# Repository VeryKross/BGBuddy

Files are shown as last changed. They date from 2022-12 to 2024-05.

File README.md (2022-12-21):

# BGBuddy
BG Buddy is a blood glucose monitoring project that provides a local IoT-based display for Nightscout users.

BG Buddy leverages the ESP8266 SOC, an inexpensive OLED display, and a few other optional components. Since BG Buddy depends on a user's Nightscout website for data, this has to be setup and operational before anything wonderful can come from BG Buddy. If you're not familiar with Nightscout, please refer to this link for all the details and come back here once you're setup: http://www.nightscout.info/

This initial version of BG Buddy simply monitors the Nightscout API and displays 5 key pieces of information which, for me, would cause me to check on a loved one with diabetes if any of the values were out of range. That's really what's at the core of BG Buddy - keep those key values top-of-mind by creating a simple inexpensive device that could sit on a desk or shelf [or both] so these critical values are always available, at a glance. See the Wiki for planned updates.



BG_Buddy1_Breadboard1

The full build and setup instructions, bill of materials and other info can be found in a PDF document in the version (v1) folder. This covers both source and compiled bin options so if you really don't want to get into compiling stuff and just want a working BG Buddy, that's an option too!

BG Buddy is a DIY project intended for educational and personal use only. It is not intended for commercial use or to be relied upon for any professional or medical purposes. The creators and contributors of BG Buddy are not responsible for any damages or injuries that may result from the use of this project. By using the BG Buddy software and/or hardware plans, you acknowledge that you understand and assume all risks associated with its use. Please use caution and common sense when working on any DIY project.

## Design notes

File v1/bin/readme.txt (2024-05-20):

The bin file here is a compiled version of the program in the src folder.

NOTE: The IdeaSpark versions are only for the IdeaSpark ESP8266 with built-in OLED screen. Don't use these if building the project from the documentation with the separate ESP8266 and SSD1306 OLED components. Note also that there are two versions of the IdeaSpark binary, SDA12 and SDA14. This corresponds to whether your particular IdeaSpark package is using the GPIO12 pin or the GPIO14 pin for the screen's data connection (OLEDSDA). Check the documentation/diagram for your IdeaSpark to know which binary is right for you. If you're not sure, reach out to me.

To install the bin file into your ESP8266 processor, use a ROM "flasher" like the one from ESPHome Flasher: https://github.com/esphome/esphome-flasher/releases

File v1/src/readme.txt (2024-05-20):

This folder contains the BG Buddy v1 source file. It can be loaded directly into 
the Arduino IDE, compiled, and flashed to your ESP8266 processor without making any changes.

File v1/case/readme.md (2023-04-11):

# 3D Printable Case
This is a [very] basic case that I created to be 3D printed for BG Buddy. I should be printable without any supports on nearly any FDM (filament style) printer, and it will work equally well with PLA, PETG or whatever your favorite filament type is.

The case is a snap together design that doesn't require any glue other than the hot glue you might use to mount the SOC and OLED screen.

In addition to the top and base of the case, I've also included a separate "frame" for the OLED - I found this to be the trickiest bit to design and so by providing it separately, I hope to make it easier for anyone else who might want to use this frame within their own case design just to save some time and trouble. If you just want the case as-is, just print the top and base and ignore the frame.

Here's a picture of the printed case using PLA with a .28 layer hight - it would come out much cleaner if you print at higher quality setting.


If you are using the IdeaSpark "all in one" processor, the one with the ESP8266 and OLED mounted together as one unit, I've uploaded a new case that works well for it. Just download and print the three IdeaSparkCase files - they don't require any supports for printing. When operating, the blue activity LED is just visible through the plastic in the top-right corner (depending on what color filament you use of course).



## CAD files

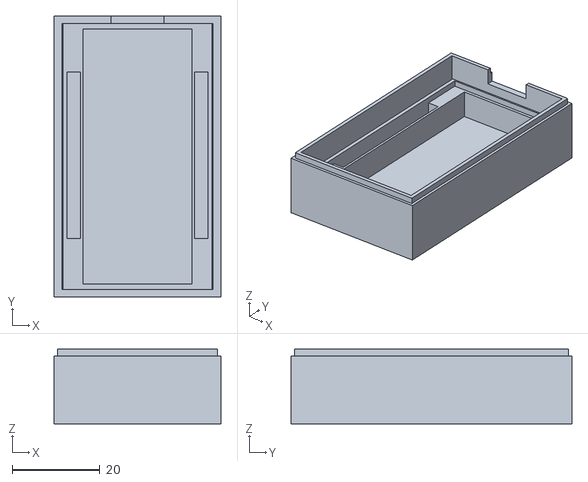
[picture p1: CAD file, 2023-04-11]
v1/case/IdeaSparkCase_Bottom3.stl
38.0 x 64.0 x 17.0

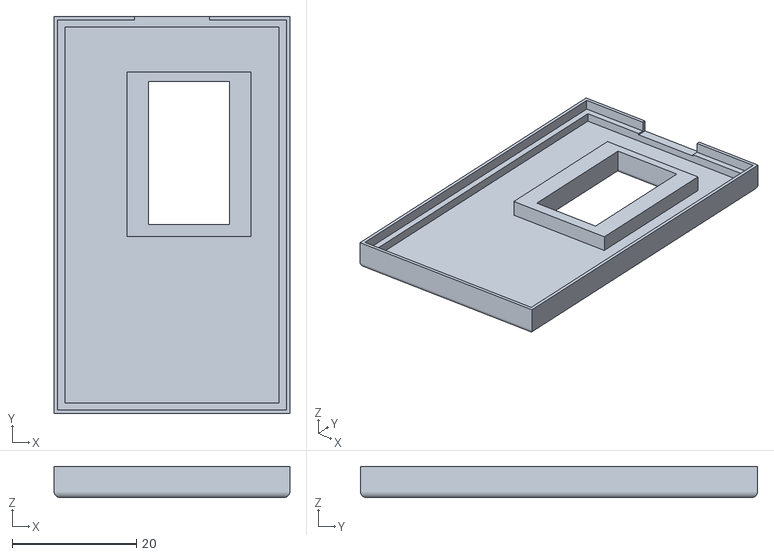
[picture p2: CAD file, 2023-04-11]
v1/case/IdeaSparkCase_Top2a.stl
38.0 x 64.0 x 5.00

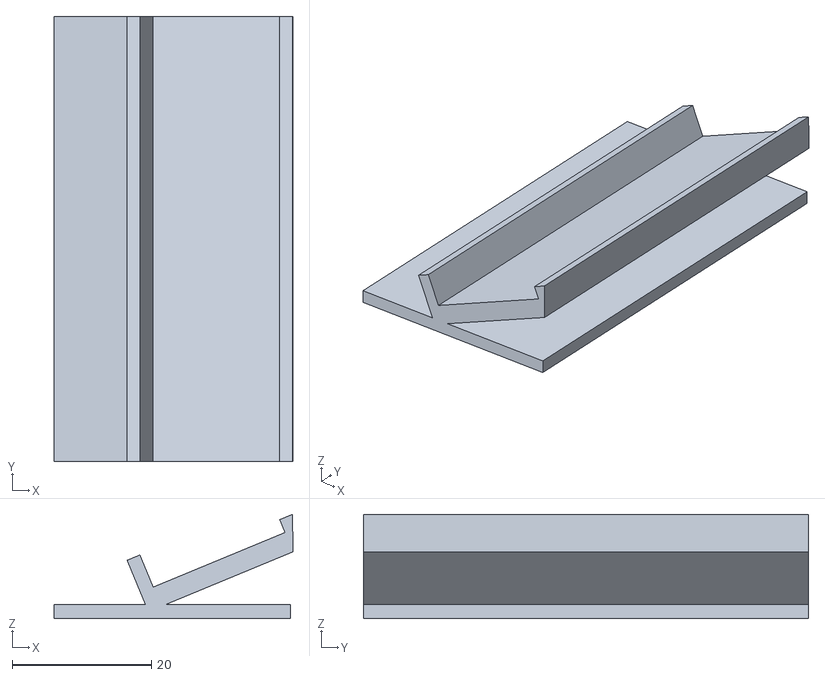
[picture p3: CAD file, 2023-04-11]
v1/case/IdeaSparkCase_Stand2.stl
34.4 x 64.0 x 15.0

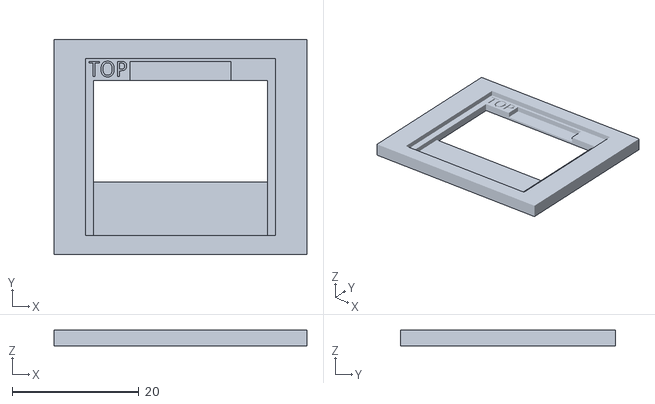
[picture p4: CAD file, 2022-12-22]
v1/case/BG Buddy_OLED_Frame.stl
40.0 x 34.0 x 2.50

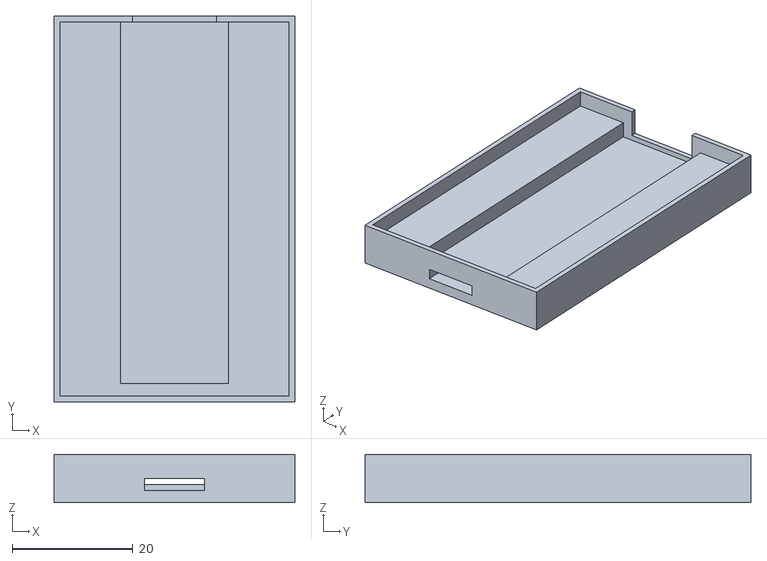
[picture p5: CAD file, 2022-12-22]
v1/case/BG Buddy_base.stl
40.0 x 64.0 x 8.00

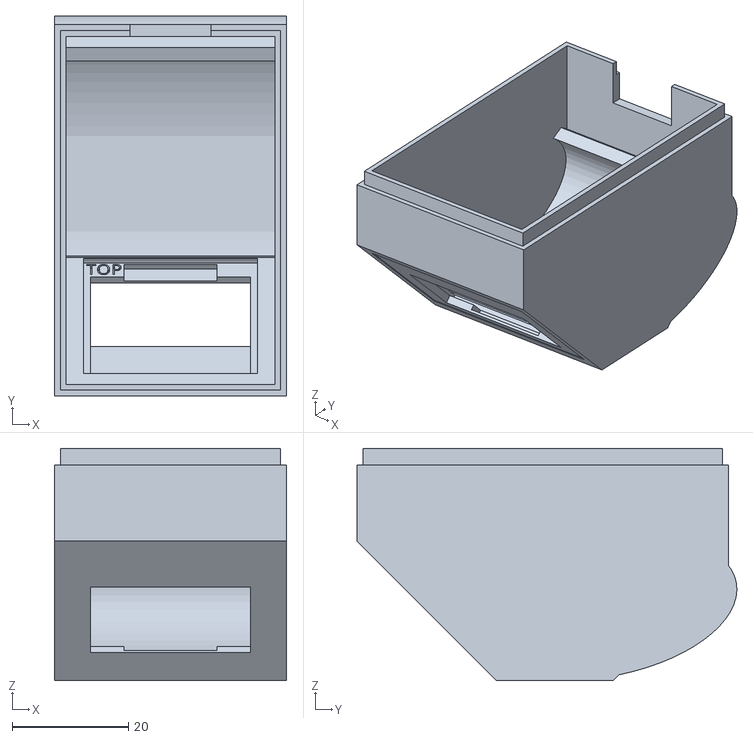
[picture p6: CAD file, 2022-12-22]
v1/case/BG Buddy_top.stl
40.0 x 65.5 x 40.0

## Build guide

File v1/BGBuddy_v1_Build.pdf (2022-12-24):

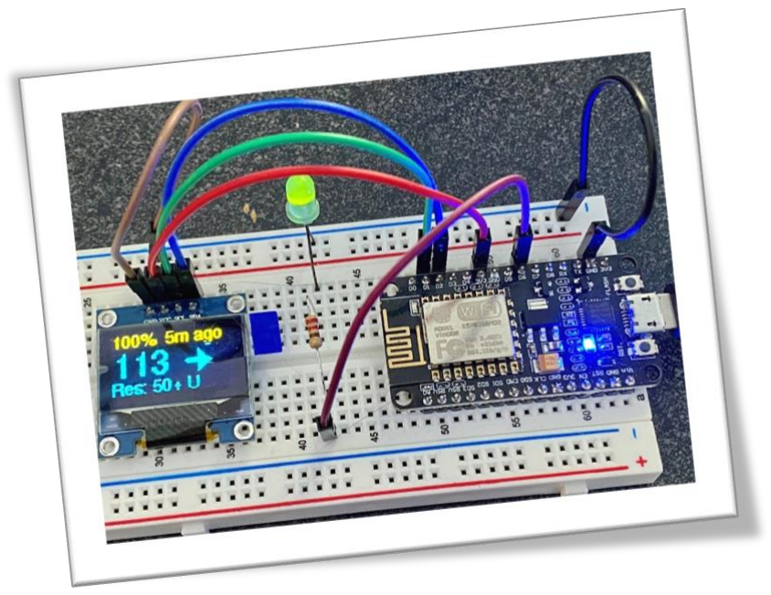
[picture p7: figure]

HTTPS://GITHUB.COM/VERYKROSS/BGBUDDY | 1

# Blood Glucose Buddy v1

## Introduction

BG Buddy is a blood glucose monitoring project that provides a local IoT-based display for Nightscout users. As such, BG Buddy is currently only usable for people that have a working Nightscout site setup that they are publishing their data to via their CGM or the Loop mobile app. It is beyond the scope of this document to explain Nightscout so please refer to this link: http://www.nightscout.info/

In terms of hardware, BG Buddy leverages the ESP8266 SOC, an inexpensive OLED display, and a few other optional components. It’s easy to put together and depending on where you get the components, you can be up-and-running for well under $20 USD!

Version 1 (v1) of BG Buddy simply monitors the Nightscout API and displays 5 key pieces of information. For me, these are the values that would cause me to get up and check on a loved one with diabetes if any of them were out of range. Really, that’s what's at the core of BG Buddy - keep those key values top-of-mind and glanceable by creating a simple, inexpensive device that can sit on a desk or shelf [or both] so that these critical values are always visible. In addition, it will also light up an LED approx. every minute when it’s refreshing the data.

Looking ahead, the next version of BG Buddy will be adding alerts in the form of both visual (another LED) and audible (buzzer). These alerts will be driven off your Nightscout alarm settings, so no additional setup is needed within BG Buddy itself. You will, however, be able to turn off the alerts [and if your version of BG Buddy doesn’t have the extra LED or buzzer, you won’t get the alerts anyway].

As is stated on our GitHub site, BG Buddy is a DIY project intended for educational and personal use only. It is not intended for commercial use or to be relied upon for any professional or medical purposes. The creators and contributors of BG Buddy are not responsible for any damages or injuries that may result from the use of this project. By using the BG Buddy software and/or hardware plans, you acknowledge that you understand and assume all risks associated with its use. Please use caution and common sense when working on any DIY project.

## Building BG Buddy

### Overview

Now, if you found that photo of a bunch of wires and gadgets plugged into some kind of board with a bunch of holes in it a little bit scary, stay with me – I got you That’s just a project “breadboard”; it’s an easy way for DIY tinkerers to play with electronics components and create circuits without having to solder wires together. If you don’t have one, and aren’t interested in getting one, no worries – we can get by without it, especially if we’re just creating a BG Buddy to use [not tinker with].

When we take a more abstract look at what makes up BG Buddy from the hardware perspective, there are just two(2) main parts and two(2) optional parts.

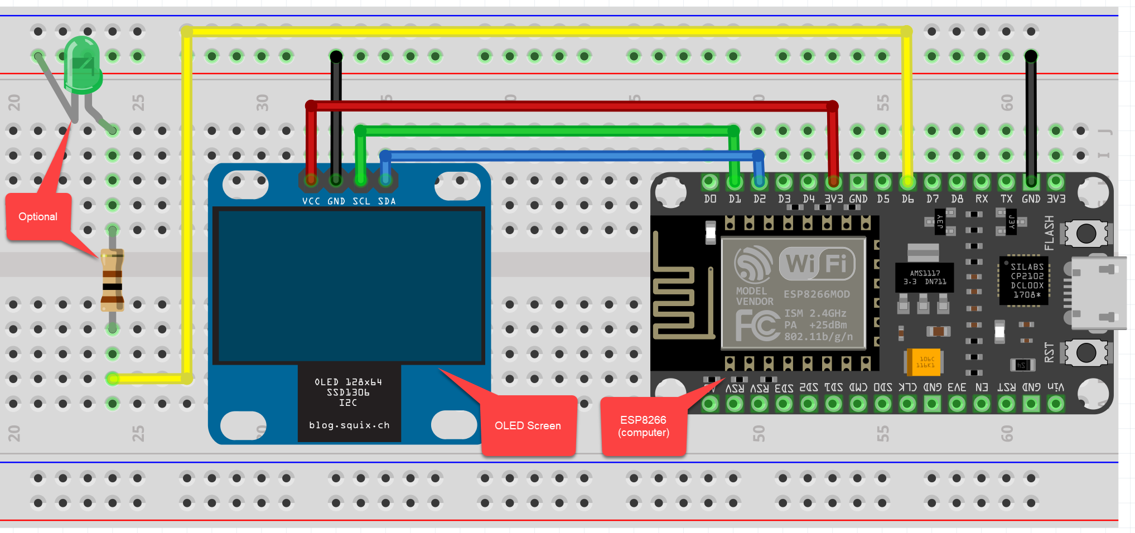
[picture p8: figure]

We need the ESP8266 since that’s the “computer” (SOC – System On a Chip) and we need the little OLED screen so we can display our BG values. The two optional components, a green LED and a resister, are used together so BG Buddy can light up a green status LED when it’s getting fresh data; if you can live without seeing that activity, you can leave those out and, besides, I also light up the blue LED built into the SOC as a secondary busy indicator so you can always refer to that.

The ESP8266 has a micro USB plug on it which is where it gets power from and is how we program it by plugging it into your PC (Windows or Mac). Once programmed, it just needs power and that can come from almost any USB charging adapter you have lying around.

The OLED screen connects to the ESP8266 with just four (4) wires; you’ll want to be careful about following the directions here because depending on the manufacturer of these OLED screens, they sometimes rearrange the order of the four(4) pins that the wires connect to so, for example, instead of VCC, GND, SCL, SDA like in the diagram above, they might be GND, VCC, SCL, SDA instead. Also, I’ll show you how to do this without any soldering to make it super easy. If you hook everything up and the screen stays blank though, double check the order of those pins first!

### Bill of Materials (BOM)

Alright, as I mentioned above, there are just two things you need; the ESP8266 SOC and the OLED. If I’m totally honest, yes, you’ll need some wires too…and probably a case…and maybe some hot glue. The point is, you don’t need much and you don’t need special tools or skills to have a fully functional BG Buddy, just like this one using just.4.wires :

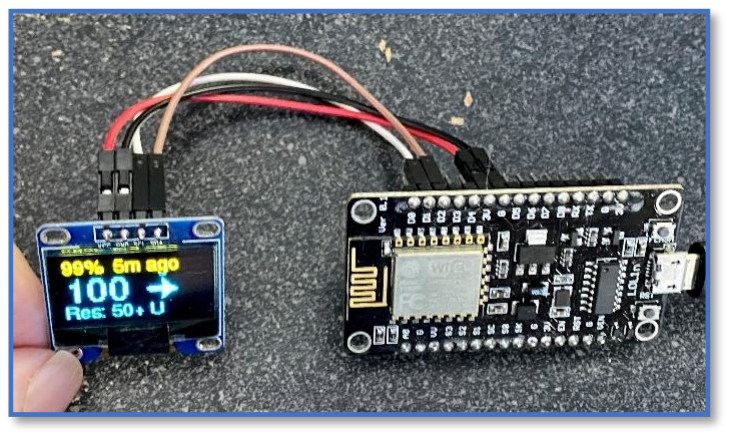
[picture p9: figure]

Now for the shopping list, I’ve tried to give you two options – ordering from Amazon or ordering from AliExpress. I’ve ordered components from both and will happily do so again; I’ve had great experiences with AliExpress, and the prices are amazing, but it will take longer to get your parts (2-3 weeks usually). You’ll also want to pay very close attention to what you’re ordering, not because they’re trying to scam you but because a single listing sometimes has several product variations, and you’ll want to be sure you’ve selected the one you want. Don’t assume that because the picture looks right, that the correct product/variation has been selected. Click it and confirm the price before adding to your cart.

The links and prices I’ve quoted are in US dollars so if you’re outside of the US, check your local sources for equivalent products. Local to me I’ve also found all of these items at local electronics stores so if you have that option, check it out.

The must have parts:

- ESP8266 SOC [the “computer”]
- Amazon: (3-pack ~$16USD) https://www.amazon.com/KeeYees-Internet-Development-Wireless-Compatible/dp/B07HF44GBT/
- Ali Express: (1 count ~ $3USD)
https://www.aliexpress.us/item/2251832478785371.html
- SSD1306 OLED [the display screen]
- Amazon: (1 count ~ $7USD) https://www.amazon.com/UCTRONICS-SSD1306-Self-Luminous-Display-Raspberry/dp/B072Q2X2LL/
- Ali Express: (1 count ~ $3.50USD - be sure to select the correct 4-pin yellow/blue display) https://www.aliexpress.us/item/2251832709890624.html
- Wires [to directly connect the above components]
- Amazon: (40 count female-to-female 4" ~ $6USD) https://www.amazon.com/dp/B077N58HFK
- Ali Express: (1 pack 40 count female-to-female 10cm [4"] ~ $2.50USD) https://www.aliexpress.us/item/2251832638800607.html

As you can see, there’s quite a price difference [between Amazon and AliExpress] and you’ll note that in some cases there’s a difference in the minimum # of parts you can order (the smallest quantity of ESP8266 devices you can buy on Amazon is a 3-pack). If you’re planning to make more than one BG Buddy, probably not a big deal. Otherwise, especially if ordering from Amazon, you may want to see if you can split an order with some other local folks who want their own BG Buddy – you’ll certainly have more than enough wire!

When we get into the optional components, like the green LED, things get worse in terms of minimum quality; it’s very hard to find LEDs in quantities of less than 60 or resisters in packs of less than 100, and you only need one(1) resister per green LED. Now, if you’re someone who likes to tinker with electronics and other DIY projects, that’s probably not an issue and even these large quantities are still very inexpensive. Of course, if you are a DIY sort of person, you probably already have some LEDs and resisters lying around

The optional parts:

- Green LED (constant or blinking variety)
- Amazon: (60 count, multi-color, non-blinking ~ $6USD) https://www.amazon.com/dp/B01C3ZZT2I
- Ali Express: (100 count, multi-color, non-blinking ~ $2.50USD) https://www.aliexpress.us/item/2251832545092387.html
- 100-220 Ohm resistor (depends on LED brightness desired)
- Amazon: (100 count 200ohm ~ $6USD) https://www.amazon.com/EDGELEC-Resistor-Tolerance-Resistance-Optional/dp/B07HDGH1R1
- Ali Express: (100 count, be sure to select 200R [for 200 ohm] ~ $3USD) https://www.aliexpress.us/item/3256801441680644.html
- Project board (aka Breadboard)
- Amazon: (board & wires kit, some components won't be needed ~ $11USD) https://www.amazon.com/dp/B09TX9CMG1
- Ali Express: (board without wires ~ $4USD) https://www.aliexpress.us/item/3256801539488877.html
- Wires for breadboard
- Amazon: (120 count 4” variety pack of female-to-female, male-to-male & male-female ~$7USD) https://www.amazon.com/dp/B07GD1XFWV?th=1

As mentioned above, you only need the green LED if you want to have a “busy” status light that you can locate wherever you’d like (handy if you want to poke it through the outside of a case). To use it, and the resister [do not try and use the LED without a resister … bad things will happen], you will almost certainly need to solder things together so be prepared for that. I’ll also point out that if you decide to upgrade to the v2 BG Buddy later, the one with alerts, you’ll be adding a red LED to the kit for the visual alert. So, if you do decide to buy a pack of LEDs, maybe make it a variety pack so you have both the green and red LEDs … just in case

The breadboard listed here is only needed if you want to start tinkering with this DIY electronics stuff – if your goal is to just assemble BG Buddy and pop it in a case, you don’t need the breadboard. Also, if you do decide to get the breadboard, you’ll need some wires in addition to those in the “must have” list – you need wires with exposed ends you can poke into the holes in the breadboard. Because of that, I’ve listed a breadboard on Amazon that comes with a set of appropriate wires for about the same price as buying a breadboard and set of wires separately.

BTW, a quick note regarding the OLED screen; you’ll see a number of varieties of this little display, some with a mix of yellow and blue text, some with all blue and some with white text. While I’ve chosen to use the yellow/blue variety in my example, they all behave the same, so it really comes down to your personal preference. The only difference that you do want to watch out for is the number of pins sticking out the back; we want the 4-pin variety, not the 7-pin version.

### Hardware Step-by-Step

The “bare bones” BG Buddy
I’m going to assume that most readers are here to just build the darn thing already and call it a day. If that’s you, and you’ve got your wires, ESP8266, and OLED display in hand, I’ll need about 5min of your time because we’re going to take it slow and easy.

To make the four(4) connections we need, we’re going to slip the ends of those wires over the pins on our two devices, pressing them in as far as they’ll go so they cover the pins completely. Which color wires you use for this really doesn’t matter but for clarity, I’ll use Red, Black, White and Brown to represent Power, Ground, Clock and Data respectively. The following table shows which color wire goes where on each device:

Wire | Purpose | ESP8266 SOC Connection | SSD1366 OLED Connection
Red | Power – 3 volts from the SOC | 3V (sometimes 3V3) | VCC
Black | Ground (GND) | G (sometimes GND) | GND
White | Clock | D1 | SCL
Brown | Data | C2 | SDA

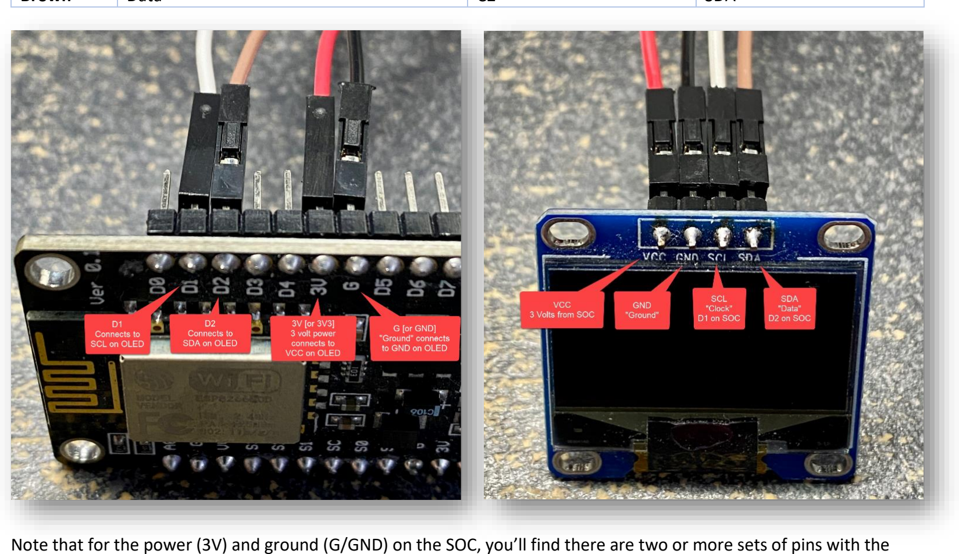
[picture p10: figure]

Note that for the power (3V) and ground (G/GND) on the SOC, you’ll find there are two or more sets of pins with the same labels. They’re interchangeable so you can pick any 3V pin and any G/GND pin, whichever is most convenient.

With those wires connected, and double check the power and ground (VCC->3v and GND->G) to make sure they’re not reversed (it’s not you, it’s the manufacturers…tricky tricksters), we’re about ready to get this programmed, setup and operation! If you plug it in right now for a “smoke test” (meaning, we really don’t want to see any smoke), not much is going to happen and the screen will likely stay blank. The only sign of life you might see would be a brief flicker from the blue LED on the SOC – not much reward for your hard work!

So, jump down to the Software section and we’ll breathe life into your new creation!

The “fancy” BG Buddy
Everything that we did in the “bare bones” version still applies here; we’re just adding the green LED to mix and connecting it following the diagram below:

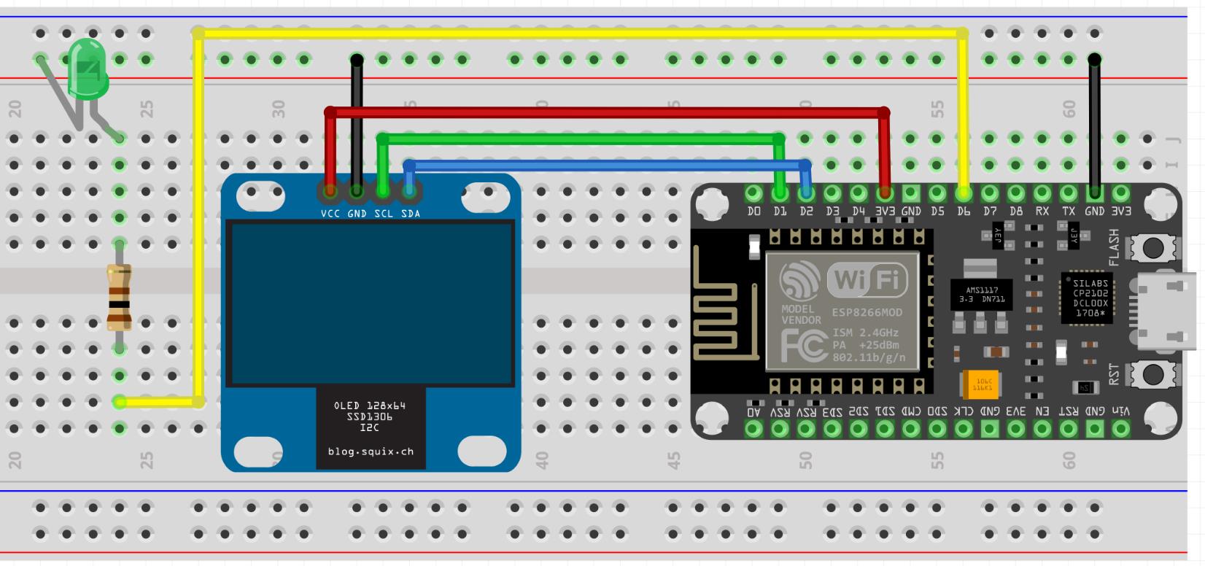
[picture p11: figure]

Now, there’s a right way and a wrong way to connect an LED; one wire goes to G/GND (“ground”) similar to the pin on our OLED screen. The other LED wire need to connect to power that can be switched on/off by our program at the appropriate times. However, it can’t connect directly to power; it has to go through a resister in order to limit the amount of power it gets (“current”) so it doesn’t burn out. The value of a resistor is measured in OHMs and for this project any value between 100 and 220 OHMs will be fine (even a little higher is okay but much higher, like 1000 OHMs, could make the LED too dim). Also, while the LED has a right way and wrong way to hook it up, the resister doesn’t; there’s no way to connect it “backwards”.

When you look at the LED you’ll notice that there’s a long wire and a short wire, and if you look closely at plastic part of the LED, you’ll notice that there’s a flat edge on the same side as the short wire. This is the side we want connected to ground. The other side, with the long wire, will connect to one side of the resister and the other side of the resister will connect to pin D6 on the SOC. Note that for maximum flexibility in terms of where you’ll be able to mount that LED in your case, you’ll probably want to connect a couple wires to the SOC [one for ground and one for D6], and then strip and solder the other ends of those wires to the LED and resister, as well as soldering the LED to the resister (feel free to cut the length of the resister and LED wires if you find them too long or awkward to work with).

This is the point in the instructions where I say that I have to assume you have some soldering experience already and that if I say “strip and tin the wires”, you’ll know what that means. If you don’t, that’s okay, but you’ll want to get just a little practice with those steps first – we’re not doing anything complicated but using a soldering iron arounds wires and electronics can cause an unexpected burn to you or overheat and damage a component if you’re not careful. This link will cover the basics so you can continue here safely: https://www.makerspaces.com/how-to-solder/

### Software

We’re almost there! Similar to the hardware build discussion though, there are two possible paths for getting the software built and installed on your new BG Buddy; let’s call them the Easy Path and the Geek Path. Also, just for the record and speaking as the geek who wrote the software, I recommend everyone take the Easy Path and then if you’re just curious or if you want to help me make BG Buddy even better, then step onto the Geek Path.

Easy Path
The easy path is simply this; I’ve already compiled the BG Buddy software into something called a “binary image” and so you can quickly and easily install that onto your SOC with no programming knowledge, complicated tools, or much of any setup. The only things you’ll need to do are:
1. Download the latest version of the binary file from the GitHub repository where it’s stored.
2. Download a “flasher” program that will take that binary file and load it (“flash” it) onto the SOC.

For step 1, you can download the binary file from here: https://github.com/VeryKross/BGBuddy/tree/main/v1/bin

- Click on the “BGBuddy_V1.bin” file listed there and on the subsequent screen, click on the “Download” button and save the file somewhere on your local computer that will be easy to find

For step 2, I recommend using the free ESPHome-Flasher utility. They have versions available for Windows, Mac and Linux and there’s really nothing to install; just download it and run it whenever you need to flash a program into memory [which we do]. You can get all versions of the utility from this page, just scroll down until you see the “Assets” section and pick the file that’s right for you (note that if you’re running Windows, it will be the ESPHome-Flasher-1.4.0-Windows-x64.exe file): https://github.com/esphome/esphome-flasher/releases

Okay, now that you have the utility we’re just about ready to go! If you haven’t done so already, make sure you have your ESP8266 SOC plugged into your PC with a USB cable. Then run the ESPHome-Flasher utility and you should see a screen something like this:

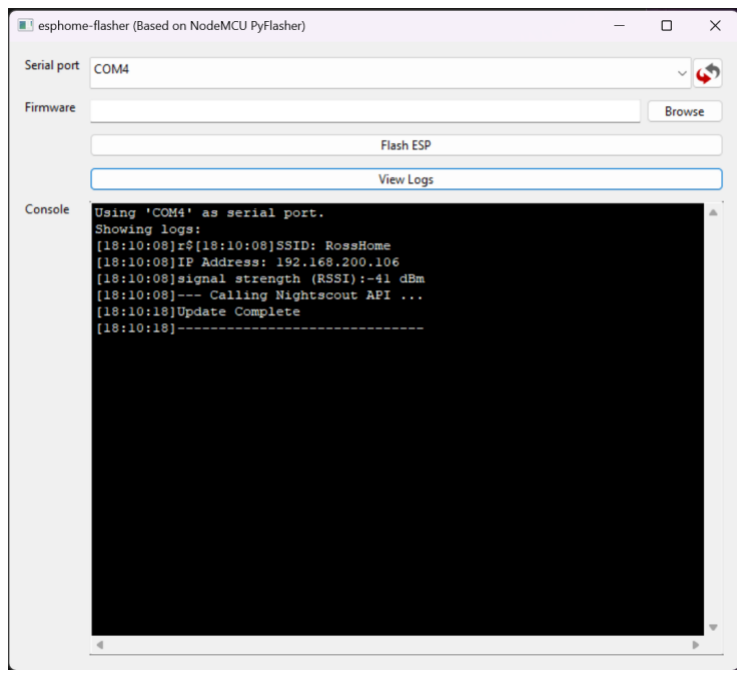
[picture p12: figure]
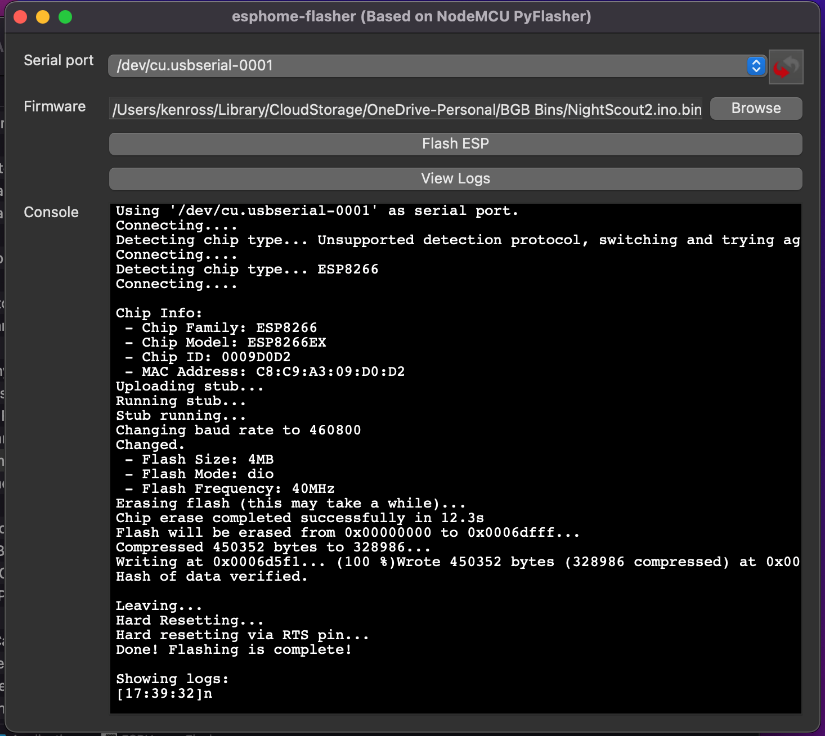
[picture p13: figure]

Windows version | macOS version

So, first things first – we need to select which communications “port” your SOC is connected to. On Windows, this will show up as “COM” followed by a number (e.g. COM4). On Mac and Linux, the port shows up as a numbered device (see the screen shot above). It’s unlikely that you’ll see more than one listed but if you do, just pick one to try and if it doesn’t work, try again with the other (not very scientific, but you’ll find the right one pretty quickly).

Once you’ve selected the port, click the Browse button and locate the BG Buddy binary file you downloaded earlier. With that selected, just click the “Flash ESP” button and you should see it run through a series of steps similar to what you see on the Mac screenshot above. The blue LED on the SOC will also flicker while this is going on. It may take a minute or so to complete so just be patient. If it’s going to fail, it will likely do so immediately, and that will probably be from having the wrong port selected; if that’s the case, pick a different port and try again.

When the flash process has completed, the SOC will automatically reset and start running the BG Buddy application! Next stop, setting up the software!

Geek Path
Who are we kidding? If you want the geek path, check out the src folder in the repo and load the sketch into your favorite Arduino IDE Be sure to add the ESP8266 devices if you haven’t already, and when selecting the board type, select “NodeMCU 1.0 (ESP-12E Module)”.

Other than that, it should all build and install onto your device without any issues. If you’re an experienced C/C++ developer, please excuse some of my code structure choices – it’s not always the most elegant as I’ve been dusting off yearly 30yrs of C/C++ neglect from my little grey cells while simultaneously learning the Arduino / ESP8266 platform and ecosystem

https://github.com/VeryKross/BGBuddy

### BG Buddy Setup for 1st Run

Setting up BG Buddy the first time requires a few manual steps but the device will prompt you through it and all you’ll need is your smartphone. Completing the following steps will have your BG Buddy talking to Nightscout in no time:

1. Connect your phone to BG Buddy’s Wi-Fi Access Point
2. Open the BG Buddy setup web page from a web browser on your phone
3. Fill in your Wi-Fi SSID and password so it knows how to connect to your network
4. Fill in your Nightscout URL (without the HTTPS:// prefix)
5. Tap Save and reboot BG Buddy (just unplug and plug back in works too)

When BG Buddy first woke up after being flashed, you should see something like this on the OLED display:

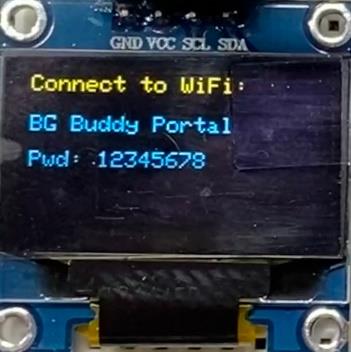
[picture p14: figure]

| This not only tells us that the software is installed and running correctly (yay!) but it’s also telling you the next steps; open the Settings in your phone, go do the Wi-Fi settings, and look for a new network called “BG Buddy Portal” and connect to it; you’ll need to provide the super-secret “12345678” password. Sometimes the connection can take up to a minute to complete so be patient.
| Once you’re fully connected, open a web browser on your phone and connect to http://10.10.10.10 – this is the address for the configuration web page during the initial setup.

You should see a web page very much like this one to the left. As long as you know your Wi-Fi name (the SSID) and the password, this should be pretty easy.

Also, just be sure when entering your Nightscout web address that you leave off the “https://” part – it won’t work if you leave it on.

For the Nightscout API Token, you can leave this blank unless you’ve specifically set up access restrictions in your Nightscout installation that requires a Token for the API. If you didn’t set up anything like that, it’s not there by default and so you can ignore that bit.

Once you’ve filled in the necessary fields you
can tap Save, restart BG Buddy, and you should
see your current BG values on the display! If you don’t see the full set of data, make sure
you have Pump and Loop checked in your
Nightscout website Settings under Plugins. It
not only affects the website display, but also the data it shares.

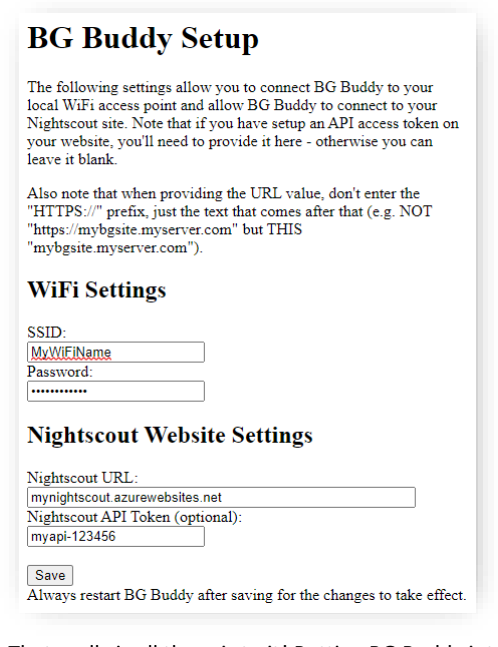
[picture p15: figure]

That really is all there is to it! Putting BG Buddy into a nice case of some sort is probably a good idea so be creative there – you can use almost anything for a case whether that’s just a small box from a craft store, a repurposed toy, or something you design and 3D print. Just make sure you have a cutout for the OLED screen and a smaller opening to plug the USB cable into your SOC. You’ll find STL files for a basic 3D printable case on the GitHub site in the “case” folder (see the last page for pictures). Mounting with hot glue is perfectly fine!

Now, if you do need to get back to that setup screen
for some reason, like maybe there is a typo in your

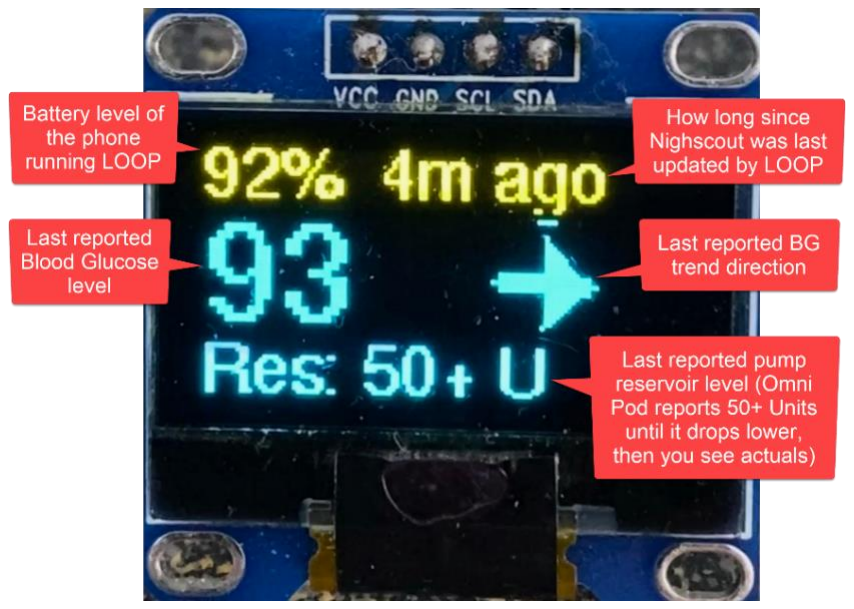
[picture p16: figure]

Nightscout URL and it can’t connect, you can just open a web browser on any computer/phone/tablet that’s connected to the same Wi-Fi network as your BG Buddy and go to this URL: http://bgbuddy.local/ This will always connect you to that setup page unless you have more than one BG Buddy on the same network. If you do, then you’ll need to connect via the IP address – not the 10.10.10.10 address, but the one that your Wi-Fi router assigned. To find out what it is, just restart your BG Buddy and watch the screen; as soon as it connects to Wi-Fi it will display its IP address at the bottom. If that number is 192.168.0.104, then in your web browser address type in http://192.168.0.104 and you’ll be connected.

Once you’re up and running, post a picture of your BG Buddy creations to social media and spread the word! If you found this useful, I’m certain others will too, and they’ll appreciate hearing about your experience putting it all together.

If you run into any trouble that restarting BG Buddy doesn’t automatically fix, send along an email to bgbuddy@hotkrossbits.com and I’ll do my best to help out.

## Basic Ugly Case Assembly – Bonus Content

Just so you can see the finished monitor in some form, I present my very basic (somewhat ugly) 3D printed case and hot-glue assembly steps. It doesn’t look like much, and I know you all will be much more creative, but this hopefully helps alleviate any remaining concerns or nervousness about final assembly Also, the STL files to 3D print this case are on the GitHub site in the “case” folder; if you print with .2mm or less layer height and default infill, you should get better results than the draft print you see here.

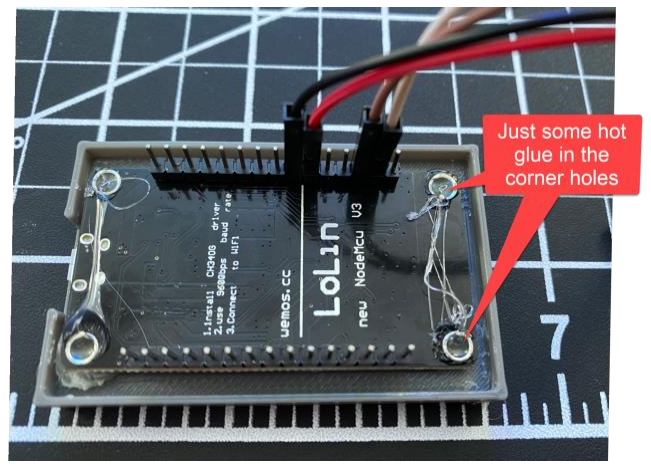
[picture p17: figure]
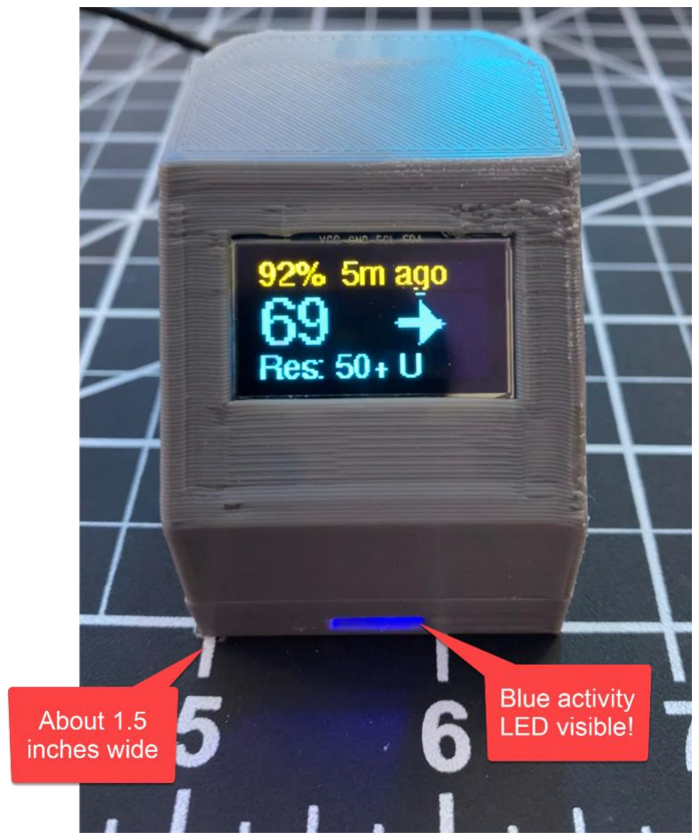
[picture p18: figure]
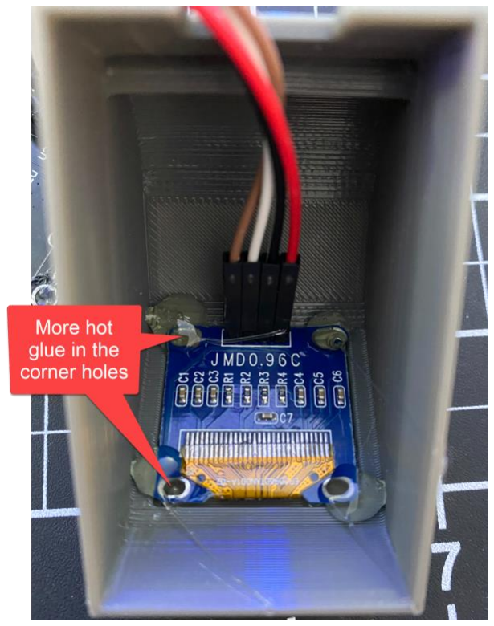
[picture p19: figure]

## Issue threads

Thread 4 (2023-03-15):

Problems compiling the sketch

sergiotome, 2023-03-15:
Hi @VeryKross!

First of all let me thank you for the amazing work you have done with this. I bought all the must have components and I'm able to set up a BG monitor for about 5€, which is great. The installation is also very simple given the instructions you provided, and loading the image with the flasher simple and quick. I have my device running already although I'm still figuring out which case to use since I don't have a 3D printer...

Having said that, I'm not a punp user, and therefore a lot of the stuff displayed in the sample screens are useless for me. They are in fact not printed at all when I flashed the firmware. But I'd like to use that space to display some other info that might be relevent in my case, such as the delta for instance, or otherwise make the reading and the arrow a little bigger to occupy the space that becomes empty since I don't have pump info available.

I loadind the ino in Arduino IDE (v2.0.4) and run into a few problems. Let me say that I'm not a C++ developer, but I have done a few things in Arduino already for M5Stack/StickC. I managed to load all the required libraries and was able to connect to the device successfully, but when I try to verify the code, I get a bunch of errors.

The first error I got is this one:
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

After some research looks like in the latest versions of C++ you cannot assign a string to a Char pointer. I fixed it by delaring the directarr variable as a string instead.

Then I also get this other error, and here is where I'm stuck and I don't know how to continue:

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

If you could help me getting that fixed it would be great. The changes I want to make are relatively simple, although if we want to make this available for everyone we could also add a property in the config page to determine whether the user is a pump user (and display certain info) or not (and display other).

Please let me know if you can help with this.

Thanks,
Sergio

VeryKross, 2023-03-15:
Hi Sergio,

Great to hear from you and thanks for the kind words! It looks like the
v2.0.4 version of the Arduino IDE introduced that char* issue; once I
upgraded my IDE from 2.0.3 I was able to reproduce the build error. I ended
up fixing it a bit differently since I was only using those characters as a
flag anyway (part of an older code change) and so I've just done away with
them and am using a bool flag which, really, is cleaner anyway.

The second output screen you're showing isn't actually an error - it's just
part of the IDE's build info. However, I *am* seeing another issue while
running - it seems that the upgrade also broke something related to how it
interprets the data coming back from Nightscout and so have to dig into
that later today and hopefully get a fix in place shortly and update GitHub
with the changes.

That said, your situation is definitely not part of the current use case;
the little beastie does current assume there's a pump involved. However,
I'm more than happy to add a non-pump option and make that configurable
since I doubt very much you're the only one running like that 😀

If you're willing to share a link to your Nightscout site, I can pull down
the JSON data that it's producing so I can better understand what our
options are. From there, you can let me know what bits of info would be
most valuable and I'll work up an alternate display layout for the
"pumpless" mode. It should be easy enough to send you a couple test images
along the way so you can easily flash your device and test.

Once it's Sergio Approved, we'll call that v1.5, update the docs, and post
the revised edition.

Ken

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

sergiotome, 2023-03-15:
Hi @VeryKross,

Thanks for the quick response. I figured earlier today that those red messages were not in fact an error, so I managed to compile and run the sketch. I'm running into other problems now though. If I flash the binary that you have [here](https://github.com/VeryKross/BGBuddy/tree/main/v1/bin) everything works nicely. I can see in the serial monitor how the device connects to nightscout every minute with a successfull processing of the response. However, if I just upload from Arduino IDE the sketch from [here](https://github.com/VeryKross/BGBuddy/tree/main/v1/src) the api connection doesn't work most of the times (although eventually it does from time to time. Here is a screenshot of my logs:

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

Something I noticed is that the Sketch is labeled as version 1, while the binary is labeled as version 1.1. Is there any change that we are missing in the source code on the repo?

sergiotome, 2023-03-15:
By the way, here is a sample JSON response from my nightscout:

```
{
	"bgnow": {
		"mean": 102,
		"last": 102,
		"mills": 1678885205604,
		"sgvs": [
			{
				"_id": "wLceE5oEDxjLBsAZkQoGB4KT",
				"mgdl": 102,
				"mills": 1678885205604,
				"device": "ABBOTT3MH0616TM7W",
				"direction": "Flat",
				"filtered": 102000,
				"unfiltered": 102000,
				"noise": 1,
				"type": "sgv",
				"scaled": 102
			}
		]
	},
	"pump": {
		"data": {
			"level": -3,
			"clock": null,
			"reservoir": null,
			"reservoir_display_override": null,
			"reservoir_level_override": null,
			"extended": null,
			"device": {
				"label": "Device"
			},
			"title": "Pump Status"
		}
	}
}
```

And here how the screen looks like for people that has no pump data

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

I see two options here for people with no pump. We can either make the reading and the arrow bigger (making it a 3 size instead of 2) and moving it down in the screen, or complete the bottom part of the screen with something like the delta, which would require adding also the delta property to the api call

VeryKross, 2023-03-15:
I've diagnosed it down to the API call itself is failing (not the JSON deserialization) but I'm not sure yet what in the Arduino update has broken it; more research this evening. We probably can't make the text any larger - I'll try it but it isn't very granular. I like the idea of finding some other useful data to display and certainly could add the delta to it.

VeryKross, 2023-03-15:
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

The "major version" is v1 but within the sketch, near the top, is a variable that holds the actual version (1.1) that is displayed. The major version or "series" will stay at v1 until v2 launches (that's where the warning and alerts will be added).

VeryKross, 2023-03-15:
Okay, so the issue is not with BGBuddy at all - it's the new version of the esp8266 board package (currently v3.1.1). There are several issues files on the 3.1.x version dealing with various http issues. It may be possible to work around them but the current "fix" is simply to revert the package back to version 3.0.2 (the latest pre-3.1.x version). One you do that, the Get functions correctly again.

VeryKross, 2023-03-16:
Also, once I push the next update, it will automatically display the Delta at the bottom if there is no pump data available.
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

sergiotome, 2023-03-16:
Ohh, nice. I will still play around with the code today if I have time, but looks like you already made the changes I was interested on. This is a great contribution to the community. Will only reach out again if I discover a bug, find something new that could be interesting to others, or to show you how my final case and set up ends up being :) thanks buddy

VeryKross, 2023-03-16:
@sergiotome I've updated the source to v1.2 and removed the v1.1 binary - we're now officially at v1.2 across the board.

Closed 2023-03-15.

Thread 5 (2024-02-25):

I can't connect to the Wi-Fi access point "BG Buddy Portal"

lexhome, 2024-02-25:
I compiled BGBuddy_v1.ino myself in Arduino IDE.
I used Wemos D1 mini as the ESP 8266.
When a mobile phone is connected to the Wi-Fi access point "BG Buddy Portal" with the password "12345678", the connection is automatically disconnected.
The following messages are displayed in the Serial Monitor:

Switching to Access Point mode ... Ready
Starting Access Point at 10.10.10.10 ...
Could not connect to WiFi - ask user to connect to Buddy.
Station connected: ee:5c:79:89:e9:72
AID: 1

VeryKross, 2024-02-25:
That's pretty unusual. Have you tried to connect to its IP address (10.10.10.10) instead of its name?  Also, have you tried just installing the pre-compiled binary instead of doing your own build? I ask because sometimes libraries change and introduce unexpected problems and I haven't had need to rebuild it in many months so it's possible that your build might be using a different library version than I used.

lexhome, 2024-02-26:
Thanks for the answer, I'll try installing the precompiled binary instead of doing my own build and report back.
In addition, I inform you that apparently this is a known problem, see for example here:
https://github.com/esp8266/Arduino/issues/1094

lexhome, 2024-02-26:
Installing the bin file using the ROM flasher did not help.
As before, when connecting to the “BG Buddy Portal” access point, the Wi-Fi connection is disconnected.

Using 'COM4' as serial port.
Connecting....%)Writing at 0x00073882... (100 %)Wrote 475312 bytes (345274 compressed) at 0x00000000 in 7.9 seconds (effective 483.7 kbit/s)...
Hash of data verified.

Leaving...
Hard Resetting...
Hard resetting via RTS pin...
Done! Flashing is complete!

Showing logs:
[21:05:38]BG Buddy
[21:05:38]Version 1.20
[21:05:38]---------------------
[21:05:38]Connecting to WiFi...
[21:05:55]Switching to Access Point mode ... Ready
[21:05:56]Starting Access Point at 10.10.10.10 ...
[21:05:56]Could not connect to WiFi - ask user to connect to Buddy.
[21:06:59]Station connected: ee:1b:1b:00:a2:5f
[21:06:59]AID: 1
[21:07:04]Station connected: ee:1b:1b:00:a2:5f
[21:07:04]AID: 1
[21:07:20]Station connected: ee:1b:1b:00:a2:5f
[21:07:20]AID: 1

lexhome, 2024-02-27:
I'm not a programmer. I tried several options, it doesn’t help, the Wi-Fi connection still drops.
Maybe it's a matter of features ESP 8266 Wemos D1 mini ?
If you upload a simple sketch from the example, the Wi-Fi connection does not break (everything is fine).

#include <ESP8266WiFi.h>

void setup() {
  Serial.begin(115200);
  WiFi.mode(WIFI_AP);
  WiFi.softAP("BG Buddy Portal", "12345678");
}

void loop() {
}

VeryKross, 2024-05-20:
Hello, I wanted to reach back out to see if you'd made any progress on this. I've just updated the binary files to version 1.3 and the focus of this update was to improve the networking, both how the WiFi was being handled and the Nightscout API calls. If you're able to, give this update a try and hopefully it will resolve any remaining issues for you.

Closed 2024-05-20.

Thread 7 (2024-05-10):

which ESP8266 card to choose ?

Odroid13, 2024-05-10:
I wanted to thank you for your project, I find it extraordinary, I will use it for sport, when I cycle for several kilometers. A visualization on my handlebars would be great ^^

After reading the PDF file, I think I can do the same thing ^^

On the aliexpress website there are 2 ESP8266 references: V3 Nodemcu-CH340 and V2 Nodemcu-CP2102

Can you confirm which one is correct?

https://fr.aliexpress.com/item/1005006861024522.html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

Also tell me if it will work with any Nightscout website? I use Render.

Also tell me if there is a possibility of lowering the screen brightness to save battery?

The glucose check is done every how many minutes please?

Thank you so much

VeryKross, 2024-05-19:
That device should work fine and of course you'll also need to get the screen and wire them up. For your purposes, you might want to consider this device which has a built-in LCD screen and basically works "out of the box" without any wiring. I have a separate binary download for this one since the pins they use to connect their display are non-standard.
https://fr.aliexpress.com/item/1005006011203112.html

I don't currently have any way to dim the LCD - it would be possible with a little extra programming.

BGBuddy should work fine for any Nightscout site running version 15.0.2 or above. The software does make some assumptions about how the site is being used though and in particular it expects that you have an insulin delivery and monitoring kit connected to the site using Loop.  It may be possible to modify BGBuddy to work with other configurations but that's been its focus up to now.

Odroid13, 2024-05-19:
I have the same card with USB-C port. The first time I used the card, the screen lit up and it said "Hello World"

https://www.aliexpress.us/item/3256805824888360.html?gatewayAdapt=fra2usa4itemAdapt

I flashed the card with the BG Buddy file “BGBuddy_v1.2_IdeaSpark.bin”. The flash is working well, I can observe in the Esphome Flasher console: the file is installed correctly and I can see in the Bg Buddy wifi networks and I can even access the 10.10.10.10 web page. But why do I have no image feedback on the screen of the ESP8266 card?

Card ESP8266 information:

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

Thanks

VeryKross, 2024-05-19:
Yes, unfortunately there aren't any standards out there that I could find. Most project examples I looked at used D1 and D2 for clock and data respectively, but when I got the IdeaSpark card it was following its own "standard". Now I see that your variation of that same design is different again.

This gets a bit trickier as more features are enabled, for example BG Buddy also supports having an external status LED that flashes the same way as the built-in blue LED on the board that is driven by pin D6. There's even a planned warning/alert feature that is currently wired to D5 for an LED and D4 for a buzzer. Unfortunately, any of those could overlap the "standard" from one of these chip+screen packages (like your GPIO12 and GPIO14 do).

I had hoped that by supporting a couple of very specific boards I could make it easier on people since the vast majority of BG Buddy users are not at all technical. What might make sense would be to add an "advanced" settings section to the BG Buddy setup page so you could remap these values if you have the information and experience to do it. That doesn't preclude adding addition pre-configured builds (like the one for IdeaSpark) but it would certainly help situations like yours.

In thinking about your specific usage, I was also wondering if it might make more sense to use an e-Ink display instead of OLED. That would use far less battery power and if BG Buddy was configured to check for new data on a slower interval, maybe every 5 or 10 minutes, that would further reduce battery by not using the WiFi. I've not tried it with an e-Ink display but it would likely require some small changes. The timing change I was considering adding anyway since for some users, checking every minute for data that only updates on Nighscout every 5 minutes doesn't add much value other than refreshing the clock.

VeryKross, 2024-05-19:
I'm getting ready to release a version 1.3 later today (improvements to connectivity and Nightscout API usage). When I do, I'll create two versions of the IdeaSpark bin file so you'll be able to give it a try. It will take much longer for me to make it all configurable but it's "on the list" :)

Odroid13, 2024-05-19:
> I'm getting ready to release a version 1.3 later today (improvements to connectivity and Nightscout API usage). When I do, I'll create two versions of the IdeaSpark bin file so you'll be able to give it a try. It will take much longer for me to make it all configurable but it's "on the list" :)

Really a good idea for configuration from the WEB page. I'm looking forward to this update, thank you very much

VeryKross, 2024-05-19:
Try this build and let me know if it works on your device.
[Uploading BGBuddy_v1.3_IdeaSpark-SDA14.zip…]()

VeryKross, 2024-05-20:
I wanted to let you know that I've now updated all of the binaries to v1.3 here on the site, including two variations for IdeaSpark. Thanks for the feedback and let me know if you have any other issues.

Closed 2024-05-20.

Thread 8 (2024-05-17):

BG Buddy Initial.... ?

spordiab, 2024-05-17:
Thank you for this great, exceptional project ^^

I have an ideaspark ESP8266MOD board with built-in screen.
The flash with the BGBuddy_v1.2_IdeaSpark.bin file works well.

Once I enter the wifi information and my web address without putting https://, I save and do a reset, when it restarts and it gives me a local IP address but then nothing, it remains like that everything the weather.

I checked several times my nightscout address was correct, on windows I copy/pasted on Chrome and I have the information from the nightscout server with my blood sugar. No need for API Token to view information.

The database is on mongodb.com and the visualization from render.com.

Can you help me please ?

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

VeryKross, 2024-05-19:
Supporting this issue via email but will update this thread once we have the issue figured out.

spordiab, 2024-05-19:
The problem was resolved.  Long live BG Buddy, thank you for everything and congratulations again for your kindness.

Closed 2024-05-19.

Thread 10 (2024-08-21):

BGBuddy v. 1.3 does not respond to disconnection Wi-Fi

lexhome, 2024-08-21:
Wi-Fi connection analysis is performed in the void setup() section. Therefore, when Wi-Fi is suddenly disconnected, the Busy LED is constantly lit and bgLevel is not updated, and the time of missed data lastUpdate does not increase

VeryKross, 2024-09-16:
Thanks for the report. I'll do some investigating to try and make this more robust.

Closed 2025-06-29.

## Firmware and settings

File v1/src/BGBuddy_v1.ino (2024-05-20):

/*
 * Author: Ken Ross
 * https://github.com/verykross
 *
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
 * A copy of the MIT License is included with this program.
 *
 */

#include <Wire.h>
#include <Adafruit_GFX.h>
#include <Adafruit_SSD1306.h>
#include <ArduinoJson.h>
#include <string.h>
#include <Arduino.h>
#include <ESP8266WiFiMulti.h>
#include <ESP8266HTTPClient.h>
#include <WiFiClientSecure.h>
#include <WiFiUdp.h>
#include <NTPClient.h>
#include <ESP8266mDNS.h>
#include <Time.h>

#include <Fonts/FreeSans9pt7b.h>

#include <ESP8266WebServer.h>
#include <EEPROM.h>

#define SCREEN_WIDTH 128  // OLED display width, in pixels
#define SCREEN_HEIGHT 64  // OLED display height, in pixels
#define OLED_RESET -1     // Reset pin # (or -1 if sharing Arduino reset pin)

#define BG_VER 1.3        // Current version of BG Buddy, displayed at startup

IPAddress local_IP(10,10,10,10);
IPAddress gateway(10,10,10,1);
IPAddress subnet(255,255,255,0);

ESP8266WebServer server(80);

WiFiEventHandler stationConnectedHandler;

WiFiClientSecure client;

int nsConnectCount = 0;
int nsRetryDelay = 15;            // Initial retry delay in seconds
int nsRetryMax = 9;               // Max # of retries before asking for help
int nsRetryNoticeThreshold = 20;  // The point at which the display will indicate a retry delay

bool askReset = false;
bool nsConnectFailed = false;
bool nsFirstUpdate = true;
bool wifiInitialized = false;
bool connectionValidated = false;
bool apMode = false;

unsigned long curMiliCount = 0;
unsigned long prevMiliCount = 0;
int nsApiInterval = 60000;        // Call the NS API every minute

struct settings {
  int initialized;
  char ssid[30];
  char password[30];
  char nsurl[50];
  char nstoken[50];
} user_settings = {};

Adafruit_SSD1306 display(SCREEN_WIDTH, SCREEN_HEIGHT, &Wire, OLED_RESET);
GFXcanvas1 dispCanvas(SCREEN_WIDTH, SCREEN_HEIGHT);

const int errorLedPin = 14; // this corresponds to pin D5 on the ESP8266 (future use)
const int busyLedPin = 12;  // this corresponds to pin D6

// Define NTP Client so we can retrieve current UTC time
WiFiUDP ntpUDP;
NTPClient timeClient(ntpUDP, "pool.ntp.org");

// This are the specific API value being retrieved; changing this will require
// changes to the parseReadings() method so best not to change it.
char apiName[] = "/api/v2/properties/bgnow,delta.display,pump.data,pump.uploader";
String serverName = "";
String apiToken = "";

// The following 5 values represent what is presented on the display
String batteryLevel=""; // Battery level of the phone running Loop
String lastUpdate="";   // How long since last Nightscout update
String bgLevel="";      // Current Blood Glucose level
String insLevel="";     // Insuline level reported by pump
String arrowDir="";     // Arrow trend direction
String levelDelta="";        // Delta change amount

void setup() {
  // Uncomment the following 3 lines for IdeaSpark ESP8266 w/OLED boards (aka IdeaSpark-SDA12)
  // int sda = 12;
  // int scl = 14;
  // Wire.begin(sda, scl);

  // Uncomment the following 3 lines for IdeaSpark Alt1 ESP8266 w/OLED boards (aka IdeaSpark-SDA14)
  // int sda = 14;
  // int scl = 12;
  // Wire.begin(sda, scl);

  Serial.begin(115200);
  display.begin(SSD1306_SWITCHCAPVCC, 0x3C);

  // Let the user know we're awake
  display.clearDisplay();
  display.setCursor(0,16);
  display.setTextSize(2);
  display.setTextColor(WHITE);
  display.println("BG Buddy");
  display.setCursor(0,32);
  display.println("Init...");
  display.setTextSize(1);
  display.println();
  display.print("Version ");
  display.println(BG_VER);
  display.display();

  // Setup the pin to control the Busy LED
  pinMode(busyLedPin, OUTPUT);
  pinMode(LED_BUILTIN, OUTPUT);
  digitalWrite(LED_BUILTIN, HIGH);

  EEPROM.begin(sizeof(struct settings) );
  EEPROM.get( 0, user_settings );

  serverName = user_settings.nsurl;
  if(String(user_settings.nstoken) != ""){
    apiToken = "?Token=" + String(user_settings.nstoken);
  }

  if(user_settings.initialized != 1) {
    wifiInitialized = false;
  } else {
    wifiInitialized = true;
  }
  
  Serial.println("BG Buddy");
  Serial.print("Version ");
  Serial.println(BG_VER);
  Serial.println("---------------------");

  Serial.printf("Connecting to WiFi... %s \n", user_settings.ssid);
  WiFi.disconnect(true);
  delay(1000);
  WiFi.mode(WIFI_STA);
  WiFi.hostname("BGBuddy");
  WiFi.begin(user_settings.ssid, user_settings.password);

  int tries = 0;
  apMode = false;
  while (WiFi.status() != WL_CONNECTED) {
    delay(1000);
    Serial.printf("%i (%i)...", tries, WiFi.status());
    if (tries++ > 20) {
      Serial.println("Switching to Access Point mode ... ");
      WiFi.disconnect(true);
      delay(1000);
      Serial.println(WiFi.softAPConfig(local_IP, gateway, subnet) ? "Ready" : "Failed!");
      WiFi.mode(WIFI_AP);
      WiFi.softAP("BG Buddy Portal", "12345678");
      Serial.println("Starting Access Point at 10.10.10.10 ...");
      stationConnectedHandler = WiFi.onSoftAPModeStationConnected(&onStationConnected);
      apMode = true;
      break;
    }
  }

  if(WiFi.getMode() == WIFI_AP){
    Serial.println("Could not connect to WiFi - ask user to connect to Buddy.");

    display.clearDisplay();
    display.setCursor(0,0);
    display.setTextSize(1);
    display.setTextColor(WHITE);
    display.println("Connect to WiFi:");
    display.setCursor(0,16);
    display.println("BG Buddy Portal");
    display.setCursor(0,32);
    display.println("Pwd: 12345678");
    display.display();
  } else {
    Serial.println("Connected to WiFi: ");
    printWiFiStatus();

    // Since we're connected to WiFi, let's display our IP address
    // In case the user wants to connect to our configuration portal
    display.clearDisplay();
    display.setCursor(0,16);
    display.setTextSize(2);
    display.setTextColor(WHITE);
    display.println("BG Buddy");
    display.setCursor(0,32);
    display.println("Init...");
    display.setTextSize(1);
    display.println();
    display.println(WiFi.localIP());
    display.display();

    // Setup mDNS so we can serve our web page at http://bgbuddy.local/
    // which is easier to remember than our IP address. Note that this
    // will only work if you have one BG Buddy on your network, otherwise
    // you'll still need to use the IP address to access each one.
    MDNS.begin("BGBuddy");
  }

  // Start the internal web server for the configuration page.
  server.on("/",  handlePortal);
  server.begin();

  client.setInsecure();
}

void loop() 
{
  MDNS.update();

  server.handleClient();

  // If user had connected to the BG Buddy access point, 
  // remind them of the IP address to browse to for setup.
  if (askReset == true) {
    display.clearDisplay();
    display.setCursor(0,0);
    display.setTextSize(1);
    display.setTextColor(WHITE);
    display.println("Once WiFi Connected");
    display.println("Browse to:");
    display.println("10.10.10.10");
    display.display();
    askReset = false;
  }  

  // Make the API call immediately after startup or roughly every minute
  curMiliCount = millis();
  if(nsFirstUpdate || curMiliCount - prevMiliCount >= nsApiInterval){
    prevMiliCount = curMiliCount;
    if(apMode == false){
      checkNSapi();
    }
  }
}

// Turns on/off LEDs to indicate activity/busy status
void showBusy(bool ledOn){
  if(ledOn){
    digitalWrite(LED_BUILTIN, LOW);
    digitalWrite(busyLedPin, HIGH); // Busy LED On
  } else {
    digitalWrite(LED_BUILTIN, HIGH);
    digitalWrite(busyLedPin, LOW); // Busy LED Off
  }
}

// Calls the Nightscout API to retrieve updated information
void checkNSapi(){
  if(wifiInitialized) {
    Serial.println("--- Calling Nightscout API ...");
    nsFirstUpdate = false;

    // If we've previously connected, the settings are likely correct so adjust our patience
    if(connectionValidated) {
      nsRetryDelay = 30;
      nsRetryMax = 50;
    }
  
    showBusy(true);

    if (!client.connect(serverName, 443) && !nsConnectFailed) {
      Serial.printf("Attempt %i of %i failed.\n", nsConnectCount + 1, nsRetryMax);
      showBusy(false);
      
      if(connectionValidated && (nsConnectCount >= nsRetryNoticeThreshold && nsConnectCount < nsRetryMax)){
        display.clearDisplay();
        display.setCursor(0,16);
        display.setTextSize(2);
        display.setTextColor(WHITE);
        display.println("API Update");
        display.println("Failing...");
        display.printf("Retry %i\n", nsConnectCount);
        display.display();
      }

      if(nsConnectCount >= nsRetryMax) {
        nsConnectCount = 0;      
        nsConnectFailed = true;
        display.clearDisplay();
        display.setCursor(0,0);
        display.setTextSize(1);
        display.setTextColor(WHITE);
        display.println("NS Connect Fail");
        display.println("Browse to:");
        display.println(WiFi.localIP());
        display.println("to check settings.");
        display.display();
      } 

      Serial.printf("Retry in %i seconds...\n", nsRetryDelay);
      nsConnectCount++;
      delay(nsRetryDelay * 1000);
      return;
    }
  
    String rawJSON = "";
    HTTPClient http;
    String apiStr = "https://" + serverName + apiName + apiToken;
    
    http.begin(client, apiStr);
    int respCode = http.GET();

    if (respCode > 0) {
      rawJSON = http.getString();
    } else {
      Serial.print("Error on HTTP request: ");
      Serial.println(respCode);
    }

    // Read the JSON response data
    JsonDocument doc;
    DeserializationError error = deserializeJson(doc, rawJSON);

    http.end();

    if (error) {
      Serial.print(F("Failed to deserialize JSON data: "));
      Serial.println(error.f_str());

      Serial.println("------------------------------");
      Serial.print("API Str: ");
      Serial.println(apiStr);
      Serial.print("Raw JSON: ");
      Serial.println(rawJSON);
      return;
    } else {
      parseReadings(doc);
    }

    showBusy(false);
    displayInfo();

    // We know we can successfully connect and process the data - huzzah!
    connectionValidated = true;
    nsConnectCount = 0;
    
    Serial.println("Update Complete");
    Serial.println("------------------------------");
  }  
  
}

// Mostly used as a debugging aid for WiFi connectivity.
// Outputs connected SSID and IP address to the serial monitor.
void printWiFiStatus() {
  // Print the SSID of the network we connected to
  Serial.print("SSID: ");
  Serial.println(WiFi.SSID());

  // Print the WiFi IP address
  IPAddress ip = WiFi.localIP();
  Serial.print("IP Address: ");
  Serial.println(ip);

  // Print the received signal strength
  long rssi = WiFi.RSSI();
  Serial.print("signal strength (RSSI):");
  Serial.print(rssi);
  Serial.println(" dBm");
  Serial.println();
}

void onStationConnected(const WiFiEventSoftAPModeStationConnected& evt) {
  Serial.print("Station connected: ");
  Serial.println(macToString(evt.mac));
  Serial.print("AID: ");
  Serial.println(evt.aid);

  if (evt.aid > 0) {
    askReset = true;
  }
}

// Utility function to return a formatted MAC address
String macToString(const unsigned char* mac) {
  char buf[20];
  snprintf(buf, sizeof(buf), "%02x:%02x:%02x:%02x:%02x:%02x",
           mac[0], mac[1], mac[2], mac[3], mac[4], mac[5]);
  return String(buf);
}

// This method is called when a user connects to BG Buddy via a web browser
// and provides an easy web-based configuration interface.
void handlePortal() {
  IPAddress userIP = server.client().remoteIP();
  Serial.print("Remote user connected to portal: ");
  Serial.println(userIP);
  String pg;
  
  if (server.method() == HTTP_POST) {

    strncpy(user_settings.ssid, server.arg("ssid").c_str(), sizeof(user_settings.ssid));
    strncpy(user_settings.password, server.arg("password").c_str(), sizeof(user_settings.password));
    strncpy(user_settings.nsurl, server.arg("nsurl").c_str(), sizeof(user_settings.nsurl));
    strncpy(user_settings.nstoken, server.arg("nstoken").c_str(), sizeof(user_settings.nstoken));
    user_settings.initialized=1;
    
    user_settings.ssid[server.arg("ssid").length()] = user_settings.password[server.arg("password").length()] = '\0';
    user_settings.nsurl[server.arg("nsurl").length()] = user_settings.nstoken[server.arg("nstoken").length()] = '\0';

    Serial.println("Updating user settings:");
    Serial.printf(" SSID: %s \n", user_settings.ssid);
    Serial.printf("  PWD: %s \n", user_settings.password);
    Serial.printf("  URL: %s \n", user_settings.nsurl);
    Serial.printf("Token: %s \n", user_settings.nstoken);

    EEPROM.put(0, user_settings);
    EEPROM.commit();

    display.clearDisplay();
    display.setTextSize(2);
    display.setTextColor(WHITE);
    display.setCursor(0,16);
    display.println("Please");
    display.println("Reset");
    display.display();

    // Save confirmation page    
    Serial.println("Configuration saved to internal memory. Please reset the device.");
    wifiInitialized = false;

    pg = "<!doctype html><html lang=\"en\"><head><meta charset=\"utf-8\"><meta name=\"viewport\" content=\"width=device-width, initial-scale=1\">";
    pg += "<title>BG Buddy Setup</title><style>*,::after,::before{box-sizing:border-box;}body{margin:0;font-family:\"Segoe UI\",Roboto,\"Helvetica Neue\",Arial,\"Noto Sans\",\"Liberation Sans\";";
    pg += "font-size:1rem;font-weight:400;line-height:1.5;color:#212529;background-color:#f5f5f5;}.form-control{display:block;width:100%; height:calc(1.5em + .75rem + 2px);border:1px solid #ced4da;";
    pg += "}button{border:1px solid transparent;color:#fff;background-color:#007bff;border-color:#007bff;padding:.5rem 1rem;font-size:1.25rem;line-height:1.5;border-radius:.3rem;width:100%}";
    pg += ".form-signin{width:100%;max-width:400px;padding:15px;margin:auto;}h1,p{text-align: center}</style> </head> <body><main class=\"form-signin\"> <h1>BG Buddy Setup</h1> <br/>";
    pg += "<p>Your settings have been saved successfully!<br/>Please restart the device.</p></main></body></html>";

  } else {

    String ssid = user_settings.ssid;
    String password = user_settings.password;
    String nsurl = user_settings.nsurl;
    String nstoken = user_settings.nstoken;

    // If we haven't initialized, all of these values will be junk and need to be cleared
    if(!wifiInitialized){
      ssid = "";
      password = "";
      nsurl = "";
      nstoken = "";
    }

    // Setup/Configuration page
    Serial.println("Configuration web page requested.");

    pg = "<!doctype html><html lang=\"en\"><head><meta charset=\"utf-8\"><meta name=\"viewport\" content=\"width=device-width, initial-scale=1\"><title>BG Buddy Setup</title>";
    pg += "</head><body><main><form action=\"/\" method=\"post\"><h1>BG Buddy Setup</h1><p>The following settings allow you to connect BG Buddy to your local WiFi access point and allow BG Buddy ";
    pg += "to connect to your Nightscout site. Note that if you have setup an API access token on your website, you'll need to provide it here - otherwise you can leave it blank.</p>";
    pg += "<p>Also note that when providing the URL value, don't enter the \"HTTPS://\" prefix, just the text that comes after that (e.g. NOT \"https://mybgsite.myserver.com\" but THIS \"mybgsite.myserver.com\").</p>";
    pg += "<h2>WiFi Settings</h2><div><div><div><div><label>SSID: </label></div><div><input name=\"ssid\" type=\"text\" value=\"" + ssid + "\"/></div></div>";
    pg += "<div><div><label>Password: </label></div><div><input name=\"password\" type=\"password\" value=\"" + password + "\"/></div></div></div></div>";
    pg += "<h2>Nightscout Website Settings</h2><div><div><div><div><label>Nightscout URL: </label></div><div><input name=\"nsurl\" type=\"text\" size=\"50\" value=\"" + nsurl + "\"/></div></div>";
    pg += "<div><div><label>Nightscout API Token (optional): </label></div><div><input name=\"nstoken\" type=\"text\" value=\"" + nstoken + "\"/></div></div></div></div>";
    pg += "<br /><button type=\"submit\">Save</button></form>Always restart BG Buddy after saving for the changes to take effect.</main></body></html>";

  }

  server.send(200, "text/html", pg);
}

// Refresh the display with current info, including drawing the trend arrow
// Canvas is used in order to avoid any update flickering
void displayInfo(){
  // Determine the trend arrow angle and offset
  int arrowOffset = 0;
  int arrowAngle = 0;
  bool hasDirection = false;
  bool doubleArrow = false;
  
  String directarr = "";

  if (String(arrowDir) == "Flat") {
    hasDirection = true;
    arrowAngle = 90;
    arrowOffset = -10;
  }  else if (String(arrowDir) == "FortyFiveUp") {
    hasDirection = true;
    arrowAngle = 45;
    arrowOffset = -5;
  }  else if (String(arrowDir) == "FortyFiveDown") {
    hasDirection = true;
    arrowAngle = 135;
    arrowOffset = -20;
  } else if (String(arrowDir) == "DoubleUp") {
    hasDirection = true;
    arrowAngle = 0;
    arrowOffset = 0;
    doubleArrow = true;
  } else if (String(arrowDir) == "DoubleDown") {
    hasDirection = true;
    arrowAngle = 179;
    arrowOffset = -22;
    doubleArrow = true;
  }  else if (String(arrowDir) == "SingleUp") {
    hasDirection = true;
    arrowAngle = 0;
    arrowOffset = 0;
  }  else if (String(arrowDir) == "SingleDown") {
    hasDirection = true;
    arrowAngle = 179;
    arrowOffset = -22;
  }

  display.clearDisplay();
  dispCanvas.setFont(&FreeSans9pt7b);

  dispCanvas.fillScreen(BLACK);
  dispCanvas.setCursor(0,12);
  dispCanvas.setTextSize(1);
  dispCanvas.setTextColor(WHITE);

  if(batteryLevel != "") {
    dispCanvas.print(batteryLevel);
    dispCanvas.print("  ");
  }
  dispCanvas.print(lastUpdate);
  
  dispCanvas.setCursor(0,42);
  dispCanvas.setTextSize(2);
  dispCanvas.setTextColor(WHITE);
  dispCanvas.print(bgLevel);

  if (hasDirection) {
    drawArrow(78, 42+arrowOffset, 10, arrowAngle, 24, 24, WHITE);
    if(doubleArrow){
      drawArrow(105, 42+arrowOffset, 10, arrowAngle, 24, 24, WHITE);
    }
  }

  dispCanvas.setCursor(0,62);
  dispCanvas.setTextSize(1);
  if(insLevel != "") {
    dispCanvas.print("Res: ");
    dispCanvas.print(insLevel);
  } else {
    dispCanvas.print("Delta: ");
    dispCanvas.print(levelDelta);
  }

  display.drawBitmap(0,0,dispCanvas.getBuffer(), SCREEN_WIDTH, SCREEN_HEIGHT, WHITE, BLACK);
  display.display();
}

// Returns the elapsed time since data updated based on the supplied epoch time
String getElapsedTime(long long epochTime){
  //setTime(epochTime);
  long long epochSec = epochTime / 1000;
  unsigned long longNow = getEpochTime();

  int seconds = longNow - epochSec;
  int minutes = seconds / 60;

  String retval = "As of Now";
  if(minutes > 0){
    if(minutes > 60) {
      int hours = minutes / 60;
      int min = minutes % 60;
      retval = "As of " + String(hours) + "h " + String(min) + "m";
    } else{
      retval = "As of " + String(minutes) + "m ago";
    }
  }
  return retval;
}

// Returns the current epoch time
unsigned long getEpochTime() {
  timeClient.update();
  unsigned long now = timeClient.getEpochTime();
  return now;
}
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

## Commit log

2022-12-14 Arduino sketch for BG Buddy v1
    Initial upload of the source for BG Buddy v1.
2022-12-20 Added revised binary.
    Handles built-in LED better for ESP8266 board variations.
2022-12-20 Update BGBuddy_v1.ino
    Changed handling of built-in LED for better support across ESP8266 variants.
2022-12-22 Update readme.md
    Added more detailed info on the 3D printable case as well as a photo of it.
2022-12-22 Add files via upload
    Added STL files for the BG Buddy 3D Printable case.
    [BG Buddy_OLED_Frame.stl, BG Buddy_base.stl, BG Buddy_top.stl]
2022-12-24 Add files via upload
    Version 1.1 of BG Buddy with changes to support mmol units as well as handling minimal Nightscout configurations (without pump info).
2022-12-24 Update BGBuddy_v1.ino
    Version 1.1 of BG Buddy with changes to support mmol units as well as handling minimal Nightscout configurations (without pump info). Also added display of version number during initial startup and m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
2022-12-24 Add files via upload
    Updated instructions to include notes re recommended Nightscout plugin settings, better BG Buddy setup screen example, and mention of the supplied STL files for a basic 3D printable case.
2023-03-16 Uploaded v1.2 build
    This build adds support for displaying the BG Delta value at the bottom of the screen if pump information isn't available.
2023-03-16 Posted updated for v1.2
    Cleans up some code and adds support for displaying Delta value below BG level if no pump information is available.
2023-04-11 IdeaSpark Case Added
    This is a simple case design for those who might be using the IdeaSpark processor (the one with the ESP8266+OLED combined).
    [IdeaSparkCase_Bottom3.stl, IdeaSparkCase_Stand2.stl, IdeaSparkCase_Top2a.stl]
2024-05-20 Update BGBuddy_v1.ino to v1.3
    Updated to v1.3 which includes improvements to WiFi connectivity and a change to how the Nightscout API was being called, allowing it to handle a larger number of configurations. Also included in this update is a second configuration for the IdeaSpark ESP8266 w/ OLED package; a user reported a package where the data and clock pins are reversed and so there will be both an "SDA12" [sda on pin 12] and "SDA14" [sda on pin 14] version of the binary.
    [BGBuddy_v1.ino]

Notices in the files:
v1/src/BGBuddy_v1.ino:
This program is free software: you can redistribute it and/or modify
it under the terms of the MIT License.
